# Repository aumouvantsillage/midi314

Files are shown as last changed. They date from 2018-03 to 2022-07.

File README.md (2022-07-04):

midi@3:14 is a home-made electronic keyboard for playing music.

This repository is no longer maintained.
Its content has been split into separate repositories available under the [Tiliosys](https://github.com/tiliosys) organization.

----

Keyboard
========

The midi@3:14 keyboard has the following characteristics:

* [Jankó](https://en.wikipedia.org/wiki/Jank%C3%B3_keyboard) layout with 3 rows of 14 keys.
* A *function key*, to assign special functions to the other keys.
* 5 potentiometers,
* USB-MIDI interface.

See the following files for more details:

* Keyboard [description](doc/Layout.md) and [layout](doc/Layout.svg).
* Printed circuit board [source files](hardware) and [bill of material](doc/BOM.md).

Firmware
========

The keyboard is equiped with an Arduino Pro Micro module.
The firmware converts user actions into MIDI events using the [MIDIUSB](https://www.arduino.cc/en/Reference/MIDIUSB)
library.

The source files for the Arduino IDE are located in the [firmware](firmware) folder.

Software
========

The [software](software) folder contains the programs that can be run on a
computer to play music and record loops.

* [midi314-display](software/midi314-display) shows the current state of the keyboard (selected program, loop states).
* [midi314-looper](software/midi314-looper) records and plays loops, and is controlled by MIDI events from the keyboard.

These programs are written in Rust and use [Jack](http://jackaudio.org/) as
the audio and MIDI interface.

The [scripts](software/scripts) folder contains a sample configuration for using the
midi@3:14 keyboard and software with [fluidsynth](http://www.fluidsynth.org/).
Fluidsynth 2 is recommended for monophonic instruments and breath controller support.
The following commands in the fluidsynth shell :

```
setbreathmode 0 0 1 1
setlegatomode 0 1
```

TODO
====

* Add metronome.
* Use metronome as a reference for the looper.
* Overdub in looper.
* Add effects.
* Record loop to a file.
* Try alternative synthesizers.
* Find a solution for safe power-off.
* Raspberry Pi: reduce boot time.
* Raspberry Pi: fix unresponsive keyboard for several seconds on boot.
* Check issue with volume after recording several loops.

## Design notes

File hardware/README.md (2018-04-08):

This folder contains the KiCad project of the midi@3:14 keyboard PCB.

Issues
======

* The PCB has no mounting holes. They must be drilled manually.
* Potentiometers have been rotated by 180 degrees from their standard orientation.
  Bourns PTV09A potentiometers have a D-shaped shaft: you can use blank knobs, or knobs with a round hole and a set-screw.
* The spacing between potentiometers is too short.
  The knob diameter must be less than 19 mm.

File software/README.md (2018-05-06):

Dependencies
============

* ALSA
* jackd
* jack-plumbing (package jack-tools) or qjackctl
* a2jmidid
* fluidsynth

```
sudo apt install a2jmidid jack-tools fluidsynth
```

Building
========

Install the Rust tool chain:

```
curl https://sh.rustup.rs -sSf | sh
source $HOME/.cargo/env
```

Build applications:

```
cd software/midi314-display
cargo build --release

cd ../midi314-looper
cargo build --release
cd -
```

Install:

```
sudo software/scripts/install.sh
```

Running
=======

Execute the `midi314.sh` script from the command line.

```
midi314.sh
```

Press a key to stop.

Building and running headless on Raspberry Pi
=============================================

Starting from an official Raspbian Stretch Lite image.
Install the dependencies and build the applications as explained in
the previous sections.

Low-latency configuration
-------------------------

Edit `/etc/security/limits.d/audio.conf`:

```
@audio - rtprio 80
@audio - memlock unlimited
```

Check that the user `pi` belongs to the `audio` group.

Reduce the swap usage:

```
sudo /sbin/sysctl -w vm.swappiness=10
```

Headless Jackd
--------------

Install Jackd without the dbus dependency:
[Running Jackd headless](https://capocasa.net/jackd-headless)

```
sudo apt install build-essential libsamplerate0-dev libasound2-dev libsndfile1-dev git

git clone git://github.com/jackaudio/jack2.git
cd jack2

./waf configure --alsa --prefix=/usr/local --libdir=/usr/lib/arm-linux-gnueabihf
./waf
sudo ./waf install
```

LCD Display
-----------

In `/boot/config.txt`, uncomment the line:

```
dtparam=spi=on
```

Run on boot
-----------

To run `midi314.sh` automatically when the board boots, do the following:

```
sudo systemctl edit midi314 --force
```

Add the following content to the service definition:

```
[Unit]
Description=midi@3:14
After=multi-user.target

[Service]
Type=idle
Environment="DEVICE=hw:0"
Environment="INTERFACE=service"
Environment="PATH=/usr/local/bin:/usr/bin:/bin"
ExecStart=/usr/bin/midi314.sh
User=pi

[Install]
WantedBy=multi-user.target
```

Enable the service:

```
sudo systemctl enable midi314.service
sudo reboot
```

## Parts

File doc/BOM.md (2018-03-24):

Keyboard
========

| Description | Reference | Provider | Qty | Unit price (USD) | Total price (USD) | Unit price (EUR) | Total price (EUR) |
|:---|:---|:---|----:|---:|---:|---:|---:|
| [Cherry MX Red Keyswitch (Linear) PCB Mounted](http://www.wasdkeyboards.com/index.php/products/keyboard-parts/cherry-mx-red-keyswitch-mx1a-l1nw-linear.html) | MX1A-L1NW | [WASD](http://www.wasdkeyboards.com) |  50 | 0.75 | 37.50 | | |
| [Row 4, Size 1x1 Cherry MX Keycap](http://www.wasdkeyboards.com/index.php/products/blank-keycap-singles/row-4-size-1x1-cherry-mx-keycap.html), Beige | R4-1X1 | [WASD](http://www.wasdkeyboards.com) |  23 | 1.00 | 23.00 | | |
| [Row 4, Size 1x1 Cherry MX Keycap](http://www.wasdkeyboards.com/index.php/products/blank-keycap-singles/row-4-size-1x1-cherry-mx-keycap.html), Charcoal | R4-1X1 | [WASD](http://www.wasdkeyboards.com) |  18 | 1.00 | 18.00 | | |
| [Row 4, Size 1x1 Cherry MX Keycap](http://www.wasdkeyboards.com/index.php/products/blank-keycap-singles/row-4-size-1x1-cherry-mx-keycap.html), Orange | R4-1X1 | [WASD](http://www.wasdkeyboards.com) | 1 | 1.00 | 1.00 | | |
| Keyboard parts shipping, USPS - First-Class Package International Service, to France | R4-1X1 | [WASD](http://www.wasdkeyboards.com) | 1 | 23.50 | 23.50 | | |
| Printed Circuit Board | | [Elecrow](https://www.elecrow.com) | 1 | 30.47 | 30.47 | | |
| Printed Circuit Board shipping, Hong-Kong DHL, to France | | [Elecrow](https://www.elecrow.com) | 1 | 20.03 | 20.03 | | |
| Printed Circuit Board customs, Hong-Kong DHL, to France | | [Elecrow](https://www.elecrow.com) | 1 | | | 23.00 | 23.00 |
| Potentiometer, Bourns PTV09A series, 10 kOhm | PTV09A-4225F-B103 | [Farnell](http://fr.farnell.com/) | 5 | | | 0.97 | 4.85 |
| Diodes | 1N4148 | [Farnell](http://fr.farnell.com/) |  50 | | | 0.682 | 3.41 |
| Components, shipping | | [Farnell](http://fr.farnell.com/) | 1 | | | 6.90 | 6.90 |
| Components, VAT | | [Farnell](http://fr.farnell.com/) | 1 | | | 3.44 | 3.44 |
| Arduino Leonardo Pro Micro ATmega32U4 | | [Chip and love](https://www.chipandlove.ch) | 1 | | | 13.00 | 13.00 |
| Knobs | | | 5 | | | | |

Computer
========

| Reference | Qty | Function |
|:---|----:|:---|
| Raspberry Pi 3 | 1 | MIDI instrument |
| LCD display | 1 | |
| Behringer U-Control UCA222 | 1 | USB sound card  |
| USB cable A-micro B | 1 | Arduino to Pi |

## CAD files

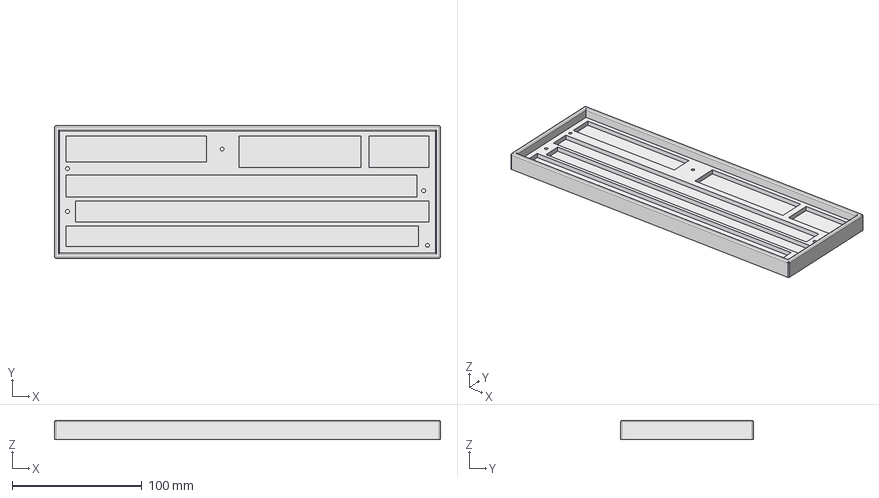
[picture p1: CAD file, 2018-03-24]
cad/midi314.fcstd
297.0 x 102.0 x 15.0 mm

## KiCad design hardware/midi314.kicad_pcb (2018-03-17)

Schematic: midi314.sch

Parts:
D11, D12, D13, D14, D15, D16, D17, D21, D22, D23, D24, D25, D26, D27, D31, D32, D33, D34, D35, D36, D37, D41, D42, D43, D44, D45, D46, D47, D51, D52, D53, D54, D55, D56, D57, D61, D62, D63, D64, D65, D66, D67: 1N4148; D_DO-35_SOD27_P10.16mm_Horizontal
RV1, RV2, RV3, RV4, RV5: POT; Potentiometer_Bourns_PTV09A-1_Single_Vertical
SW11, SW12, SW13, SW14, SW15, SW16, SW17, SW21, SW22, SW23, SW24, SW25, SW26, SW27, SW31, SW32, SW33, SW34, SW35, SW36, SW37, SW41, SW42, SW43, SW44, SW45, SW46, SW47, SW51, SW52, SW53, SW54, SW55, SW56, SW57, SW61, SW62, SW63, SW64, SW65, SW66, SW67: SW_Push; SW_Cherry_MX1A_1.00u_PCB
U1: Arduino_Pro_Micro; DIP-24_W15.24mm

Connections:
+5V: RV1.1, RV2.1, RV3.1, RV4.1, RV5.1, U1.21 (VCC)
COL1: D11.1, D21.1, D31.1, D41.1, D51.1, D61.1, U1.13 (D10)
COL2: D12.1, D22.1, D32.1, D42.1, D52.1, D62.1, U1.14 (D16)
COL3: D13.1, D23.1, D33.1, D43.1, D53.1, D63.1, U1.15 (D14)
COL4: D14.1, D24.1, D34.1, D44.1, D54.1, D64.1, U1.16 (D15)
COL5: D15.1, D25.1, D35.1, D45.1, D55.1, D65.1, U1.17 (D18)
COL6: D16.1, D26.1, D36.1, D46.1, D56.1, D66.1, U1.18 (D19)
COL7: D17.1, D27.1, D37.1, D47.1, D57.1, D67.1, U1.19 (D20)
GND: RV1.3, RV2.3, RV3.3, RV4.3, RV5.3, U1.4 (GND)
unnamed: D11.2, SW11.1
unnamed: D12.2, SW12.1
unnamed: D13.2, SW13.1
unnamed: D14.2, SW14.1
unnamed: D15.2, SW15.1
unnamed: D16.2, SW16.1
unnamed: D17.2, SW17.1
unnamed: D21.2, SW21.1
unnamed: D22.2, SW22.1
unnamed: D23.2, SW23.1
unnamed: D24.2, SW24.1
unnamed: D25.2, SW25.1
unnamed: D26.2, SW26.1
unnamed: D27.2, SW27.1
unnamed: D31.2, SW31.1
unnamed: D32.2, SW32.1
unnamed: D33.2, SW33.1
unnamed: D34.2, SW34.1
unnamed: D35.2, SW35.1
unnamed: D36.2, SW36.1
unnamed: D37.2, SW37.1
unnamed: D41.2, SW41.1
unnamed: D42.2, SW42.1
unnamed: D43.2, SW43.1
unnamed: D44.2, SW44.1
unnamed: D45.2, SW45.1
unnamed: D46.2, SW46.1
unnamed: D47.2, SW47.1
unnamed: D51.2, SW51.1
unnamed: D52.2, SW52.1
unnamed: D53.2, SW53.1
unnamed: D54.2, SW54.1
unnamed: D55.2, SW55.1
unnamed: D56.2, SW56.1
unnamed: D57.2, SW57.1
unnamed: D61.2, SW61.1
unnamed: D62.2, SW62.1
unnamed: D63.2, SW63.1
unnamed: D64.2, SW64.1
unnamed: D65.2, SW65.1
unnamed: D66.2, SW66.1
unnamed: D67.2, SW67.1
unnamed: RV1.2, U1.7 (D4)
unnamed: RV2.2, U1.9 (D6)
unnamed: RV3.2, U1.11 (D8)
unnamed: RV4.2, U1.12 (D9)
unnamed: RV5.2, U1.20 (D21)
ROW1: SW11.2, SW12.2, SW13.2, SW14.2, SW15.2, SW16.2, SW17.2, U1.10 (D7)
ROW2: SW21.2, SW22.2, SW23.2, SW24.2, SW25.2, SW26.2, SW27.2, U1.8 (D5)
ROW3: SW31.2, SW32.2, SW33.2, SW34.2, SW35.2, SW36.2, SW37.2, U1.6 (D3)
ROW4: SW41.2, SW42.2, SW43.2, SW44.2, SW45.2, SW46.2, SW47.2, U1.5 (D2)
ROW5: SW51.2, SW52.2, SW53.2, SW54.2, SW55.2, SW56.2, SW57.2, U1.2 (D0)
ROW6: SW61.2, SW62.2, SW63.2, SW64.2, SW65.2, SW66.2, SW67.2, U1.1 (D1)

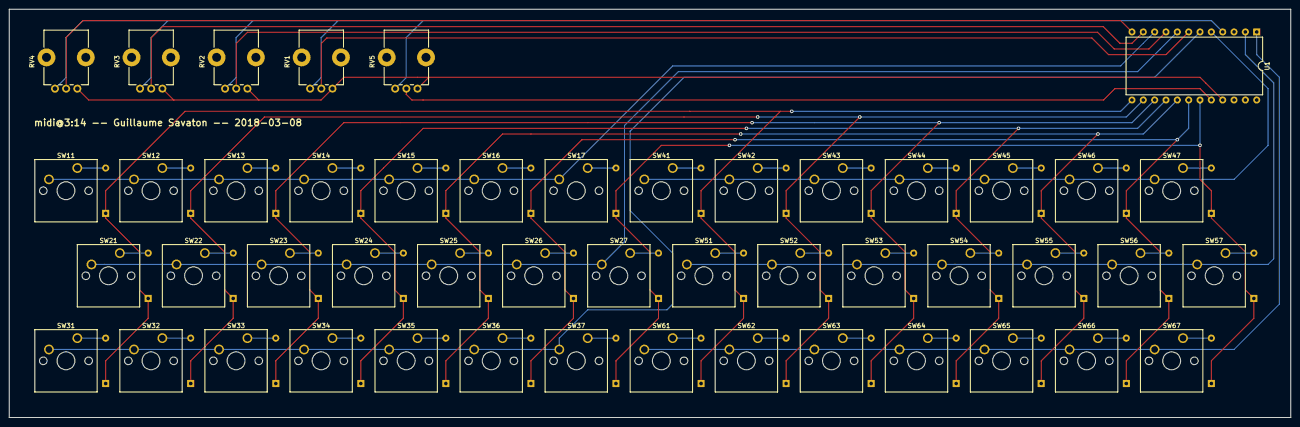
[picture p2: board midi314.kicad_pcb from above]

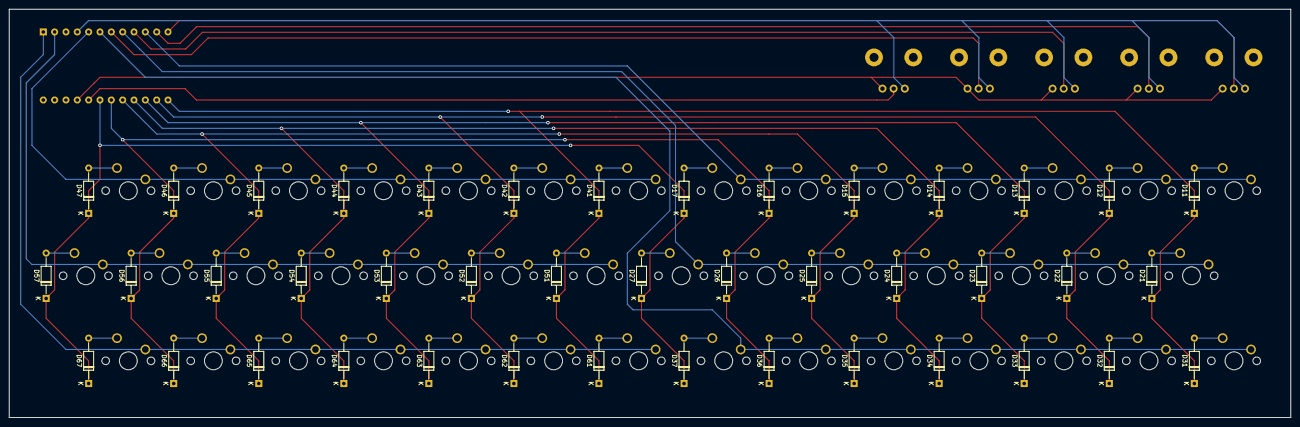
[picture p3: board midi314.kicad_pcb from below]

Board: 2 copper layers, 287.0 x 91.4 mm, 90 parts (42 on the bottom side), 62 nets.

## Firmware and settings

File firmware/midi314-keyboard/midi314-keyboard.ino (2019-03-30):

#include <pitchToNote.h>
#include <TimerThree.h>
#include <midi314.h>

// Pins connected to each row of the keyboard (from top to bottom).
static const byte rowPins[] = {7, 5, 3, 2, 0, 1};

// Pins connected to each column of the keyboard (from left to right).
static const byte colPins[] = {10, 16, 14, 15, 18, 19, 20};

// Pins connected to each potentiometer (from left to right).
static const byte potPins[] = {A9, A8, A7, A6, A3};

// The number of keyboard rows.
#define ROWS sizeof(rowPins)

// The number of keyboard columns.
#define COLS sizeof(colPins)

// The step between consecutive potetiometer stops.
#define POT_STEP 8

// The hysteresis threshold to update the potentiometer value.
#define POT_MARGIN 2

// The number of potentiometers.
#define POTS sizeof(potPins)

// The time to validate a steady state of a key, in milliseconds.
#define BOUNCE_TIME_MS 5

// The number of consecutive milliseconds in the pressed state for each key.
static byte keyPressedTimeMs[ROWS][COLS];

// The number of consecutive milliseconds in the released state for each key.
static byte keyReleasedTimeMs[ROWS][COLS];

// The pressed state for each key after debouncing.
static bool keyPressed[ROWS][COLS];

// The default pitch associated with each key.
static const byte keyNotes[ROWS][COLS] = {
    pitchC3,  pitchD3,  pitchE3,  pitchG3b, pitchA3b, pitchB3b, pitchC4,  // Top row, left
    pitchD3b, pitchE3b, pitchF3,  pitchG3,  pitchA3,  pitchB3,  pitchD4b, // Middle row, left
    pitchC3,  pitchD3,  pitchE3,  pitchG3b, pitchA3b, pitchB3b, pitchC4,  // Bottom row, left
    pitchD4,  pitchE4,  pitchG4b, pitchA4b, pitchB4b, pitchC5,  pitchD5,  // Top row, right
    pitchE4b, pitchF4,  pitchG4,  pitchA4,  pitchB4,  pitchD5b, pitchE5b, // Middle row, right
    pitchD4,  pitchE4,  pitchG4b, pitchA4b, pitchB4b, pitchC5,  pitchD5   // Bottom row, right
};

// The percussion number associated with each key.
// Not used: 58, 69, 71, 72, 73, 74, 75
static const byte keyPerc[ROWS][COLS] = {
    0,  61, 60, 64, 63, 62, 66, // Top row, left
    42, 44, 46, 49, 51, 52, 55, // Middle row, left
    35, 36, 38, 40, 37, 41, 43, // Bottom row, left
    65, 68, 67, 77, 76, 79, 78, // Top row, right
    57, 59, 54, 53, 56, 80, 81, // Middle row, right
    45, 47, 48, 50, 69, 70, 39  // Bottom row, right
};

// Indicates whether a note is playing for each key.
static bool keyNoteOn[ROWS][COLS];

// Function ids for keys.
enum {
    KEY_NONE   = 0x00,

    KEY_FN     = 0xFF,

    KEY_OCTAVE = 0x10,
    KEY_SEMI   = 0x20,
    KEY_PROG   = 0x30,
    KEY_TEMPO  = 0x40,
    KEY_LOOP   = 0x50,
    KEY_PERC   = 0x60,
    KEY_MONO   = 0x70,
    KEY_PANIC  = 0x80,

    // Multi-purpose Up/Down key codes, to be combined with
    // KEY_OCTAVE, KEY_SEMI, KEY_PROG, KEY_TEMPO.
    KEY_DOWN   = 0x0F,
    KEY_UP     = 0x0E,

    // Loop control key codes, to be combined with KEY_LOOP.
    KEY_DEL    = 0x0F,
    KEY_SOLO   = 0x0E,
    KEY_ALL    = 0x0D
};

// The special functions associated with each key.
static const byte keyFn[ROWS][COLS] = {
    KEY_FN,            KEY_OCTAVE|KEY_DOWN, KEY_OCTAVE|KEY_UP,  KEY_TEMPO|KEY_DOWN, KEY_TEMPO|KEY_NONE, KEY_TEMPO|KEY_UP,   KEY_NONE,        // Top row, left
    KEY_SEMI|KEY_DOWN, KEY_SEMI  |KEY_UP,   KEY_PROG  |0,       KEY_PROG |1,        KEY_PROG |2,        KEY_PROG |3,        KEY_PROG|4,      // Middle row, left
    KEY_LOOP|KEY_DEL,  KEY_LOOP  |KEY_SOLO, KEY_LOOP  |KEY_ALL, KEY_LOOP |0,        KEY_LOOP |1,        KEY_LOOP |2,        KEY_LOOP|3,      // Bottom row, left
    KEY_NONE,          KEY_NONE,            KEY_NONE,           KEY_NONE,           KEY_NONE,           KEY_MONO,           KEY_PERC,        // Top row, right
    KEY_PROG|5,        KEY_PROG  |6,        KEY_PROG  |7,       KEY_PROG |8,        KEY_PROG |9,        KEY_PROG |KEY_DOWN, KEY_PROG|KEY_UP, // Middle row, right
    KEY_LOOP|4,        KEY_LOOP  |5,        KEY_LOOP  |6,       KEY_LOOP |7,        KEY_LOOP |8,        KEY_NONE,           KEY_PANIC        // Bottom row, right
};

#define FN_KEY_PRESSED keyPressed[0][0]
#define DEL_KEY_PRESSED keyPressed[2][0]
#define SOLO_KEY_PRESSED keyPressed[2][1]

// The value of each potentiometer, range 0 to 127.
static byte potValues[POTS];

// The default note velocity.
#define VELOCITY 127

// The pitch of the bottom-left key.
static int pitchOffset;

// The MIDI program mapped to key P1.
static int midiProgramOffset;

// The current MIDI program number.
static byte midiProgram;

// The number of the current loop.
static byte currentLoop;

// The number of supported loops.
#define LOOPS 9

enum {
    LOOP_EMPTY,
    LOOP_RECORDING,
    LOOP_PLAYING,
    LOOP_MUTED
};

// The current state of each loop.
static byte loopState[LOOPS];

// The current MIDI channel.
static byte midiChannel;

// The current mono/polyphonic mode.
static bool monoMode;

// The default assignment of potentiometers.
static const byte potFn[] = {POT_VOLUME, POT_PAN, POT_REVERB, POT_CHORUS, POT_MODULATION};

static void scan() {
    // All column output pins are supposed to be high before scanning.
    // Scan the keyboard column-wise.
    for (int c = 0; c < COLS; c ++) {
        // Enable the current column.
        digitalWrite(colPins[c], 0);

        // Read the current state of each key in the current column.
        for (int r = 0; r < ROWS; r ++) {
            bool keyStatus = !digitalRead(rowPins[r]);

            if (keyStatus) {
                // A key-pressed event is valid if the key was released for a sufficient time.
                if (!keyPressed[r][c] && keyReleasedTimeMs[r][c] == BOUNCE_TIME_MS) {
                    keyPressed[r][c] = true;
                    midi314.pushEvent(PRESS_EVENT, r, c);
                }

                // Count the time in the pressed state. Reset the released state counter.
                if (keyPressedTimeMs[r][c] < BOUNCE_TIME_MS) {
                    keyPressedTimeMs[r][c] ++;
                }

                keyReleasedTimeMs[r][c] = 0;
            }
            else {
                // A key-released event is valid if the key was pressed for a sufficient time.
                if (keyPressed[r][c] && keyPressedTimeMs[r][c] == BOUNCE_TIME_MS) {
                    keyPressed[r][c] = false;
                    midi314.pushEvent(RELEASE_EVENT, r, c);
                }

                // Count the time in the released state. Reset the pressed state counter.
                if (keyReleasedTimeMs[r][c] < BOUNCE_TIME_MS) {
                    keyReleasedTimeMs[r][c] ++;
                }

                keyPressedTimeMs[r][c] = 0;
            }
        }

        // Disable the current column.
        digitalWrite(colPins[c], 1);
    }

    // Read potentiometer values.
    for (int p = 0; p < POTS; p ++) {
        int analogPrev = (int)potValues[p] * POT_STEP;
        int analog = analogRead(potPins[p]);
        if (analog > analogPrev + POT_STEP + POT_MARGIN ||
            analog < analogPrev - POT_MARGIN) {
            potValues[p] = analog / POT_STEP;
            midi314.pushEvent(POT_EVENT, p);
        }
    }
}

static inline int getMinPitch() {
    return pitchOffset + keyNotes[2][0];
}

static inline int getMaxPitch() {
    return pitchOffset + keyNotes[ROWS-2][COLS-1];
}

static bool isRecording;

static inline void stopRecording() {
    loopState[currentLoop] = LOOP_PLAYING;
    isRecording = false;
    midi314.controlChange(DEFAULT_MIDI_CHANNEL, MIDI_CC_CUSTOM_PLAY, currentLoop);
}

static inline void updatePitchOffset(int n) {
    if (n < 0 && getMinPitch() + n >= pitchA0 || n > 0 && getMaxPitch() + n <= pitchC8) {
        pitchOffset += n;
    }
    midi314.controlChange(DEFAULT_MIDI_CHANNEL, MIDI_CC_CUSTOM_SET_MIN_PITCH, getMinPitch());
}

static inline void updateMidiProgramOffset(int n) {
    int nextOffset = midiProgramOffset + n;
    if (nextOffset < 0) {
        midiProgramOffset = 120;
    }
    else if (nextOffset > 120) {
        midiProgramOffset = 0;
    }
    else {
        midiProgramOffset = nextOffset;
    }
    midi314.controlChange(DEFAULT_MIDI_CHANNEL, MIDI_CC_CUSTOM_SET_MIN_PROGRAM, midiProgramOffset);
}

static void playSolo(int n) {
    if (loopState[n] == LOOP_MUTED) {
        loopState[n] = LOOP_PLAYING;
    }
    for (int i = 0; i < LOOPS; i ++) {
        if (i != n && loopState[i] == LOOP_PLAYING) {
            loopState[i] = LOOP_MUTED;
        }
    }
    midi314.controlChange(DEFAULT_MIDI_CHANNEL, MIDI_CC_CUSTOM_SOLO, n);
}

static void playAllLoops() {
    // Unmute all muted loops.
    for (int i = 0; i < LOOPS; i ++) {
        if (loopState[i] == LOOP_MUTED) {
            loopState[i] = LOOP_PLAYING;
        }
    }
    midi314.controlChange(DEFAULT_MIDI_CHANNEL, MIDI_CC_CUSTOM_ALL, 0);
}

static inline void updateLoop(int n) {
    switch (loopState[n]) {
        case LOOP_EMPTY:
            if (!DEL_KEY_PRESSED && !isRecording) {
                loopState[n] = LOOP_RECORDING;
                currentLoop = n;
                isRecording = true;
                midi314.controlChange(DEFAULT_MIDI_CHANNEL, MIDI_CC_CUSTOM_RECORD, n);
            }
            break;
        case LOOP_PLAYING:
            if (DEL_KEY_PRESSED) {
                loopState[n] = LOOP_EMPTY;
                midi314.controlChange(DEFAULT_MIDI_CHANNEL, MIDI_CC_CUSTOM_DELETE, n);
            }
            else if (SOLO_KEY_PRESSED) {
                playSolo(n);
            }
            else {
                loopState[n] = LOOP_MUTED;
                midi314.controlChange(DEFAULT_MIDI_CHANNEL, MIDI_CC_CUSTOM_MUTE, n);
            }
            break;
        case LOOP_MUTED:
            if (DEL_KEY_PRESSED) {
                loopState[n] = LOOP_EMPTY;
                midi314.controlChange(DEFAULT_MIDI_CHANNEL, MIDI_CC_CUSTOM_DELETE, n);
            }
            else if (SOLO_KEY_PRESSED) {
                playSolo(n);
            }
            else {
                loopState[n] = LOOP_PLAYING;
                midi314.controlChange(DEFAULT_MIDI_CHANNEL, MIDI_CC_CUSTOM_PLAY, n);
            }
            break;
    }
}

static void forcePotEvents() {
    for (int p = 0; p < POTS; p ++) {
        midi314.pushEvent(POT_EVENT, p);
    }
}

static void processFunctionKey(int r, int c) {
    byte fn  = keyFn[r][c] & 0xF0;
    byte arg = keyFn[r][c] & 0x0F;

    switch (fn) {
        case KEY_OCTAVE:
            updatePitchOffset(arg == KEY_UP ? 12 : -12);
            break;
        case KEY_SEMI:
            updatePitchOffset(arg == KEY_UP ? 1 : -1);
            break;
        case KEY_PERC:
            if (midiChannel == DEFAULT_MIDI_CHANNEL) {
                midiChannel = PERC_MIDI_CHANNEL;
                midi314.controlChange(DEFAULT_MIDI_CHANNEL, MIDI_CC_CUSTOM_PERCUSSION, 127);
            }
            else {
                midiChannel = DEFAULT_MIDI_CHANNEL;
                midi314.controlChange(DEFAULT_MIDI_CHANNEL, MIDI_CC_CUSTOM_PERCUSSION, 0);
            }
            forcePotEvents();
            break;
        case KEY_MONO:
            monoMode = !monoMode;
            if (monoMode) {
                midi314.controlChange(midiChannel, MIDI_CC_MONO_MODE_ON, 0);
            }
            else {
                midi314.controlChange(midiChannel, MIDI_CC_POLY_MODE_ON, 0);
            }
            break;
        case KEY_PROG:
            if (midiChannel != PERC_MIDI_CHANNEL) {
                switch (arg) {
                    case KEY_DOWN:
                        updateMidiProgramOffset(-10);
                        break;
                    case KEY_UP:
                        updateMidiProgramOffset(10);
                        break;
                    default:
                        midiProgram = (midiProgramOffset + arg) % 128;
                        midi314.programChange(midiChannel, midiProgram);
                }
            }
            break;
        case KEY_TEMPO:
            // TODO Not implemented.
            break;
        case KEY_LOOP:
            switch (arg) {
                case KEY_ALL:
                    playAllLoops();
                    break;
                case KEY_SOLO:
                case KEY_DEL:
                    break;
                default:
                    updateLoop(arg);
            }
            break;
        case KEY_PANIC:
            midi314.controlChange(DEFAULT_MIDI_CHANNEL, MIDI_CC_ALL_NOTES_OFF, 0);
            break;
    }
}

static inline byte getNote(int r, int c) {
    return midiChannel == PERC_MIDI_CHANNEL ?
        keyPerc[r][c] :
        pitchOffset + keyNotes[r][c];
}

static void processEvents() {
    while (midi314.hasEvent()) {
        Event evt;
        midi314.pullEvent(&evt);

        byte potValue;

        switch (evt.kind) {
            case POT_EVENT:
                midi314.processPotEvent(midiChannel, potFn[evt.row], potValues[evt.row]);
                break;

            case PRESS_EVENT:
                if (keyFn[evt.row][evt.col] == KEY_FN) {
                    if (isRecording) {
                        stopRecording();
                    }
                }
                else if (FN_KEY_PRESSED) {
                    processFunctionKey(evt.row, evt.col);
                }
                else {
                    keyNoteOn[evt.row][evt.col] = true;
                    midi314.noteOn(midiChannel, getNote(evt.row, evt.col), VELOCITY);
                }
                break;

            case RELEASE_EVENT:
                if (keyNoteOn[evt.row][evt.col]) {
                    keyNoteOn[evt.row][evt.col] = false;
                    midi314.noteOff(midiChannel, getNote(evt.row, evt.col), VELOCITY);
                }
                break;
        }
    }
}

static void reset() {
    midi314.reset();

    // Read the initial potentiometer values.
    for (int p = 0; p < POTS; p ++) {
        potValues[p] = analogRead(potPins[p]) / POT_STEP;
        midi314.pushEvent(POT_EVENT, p);
    }

    pitchOffset = 0;
    midiChannel = DEFAULT_MIDI_CHANNEL;
    midiProgramOffset = 0;
    midiProgram = 0;
    currentLoop = 0;
    isRecording = false;
    monoMode = false;

    // FIXME send MIDI events to ensure this state is consistent with synth

    for (int l = 0; l < LOOPS; l ++) {
        loopState[l] = LOOP_EMPTY;
    }

    Serial.println("Ready");
}

void setup() {
    // Keyboard rows are attached to input pins with pull-ups.
    for (int r = 0; r < ROWS; r ++) {
        pinMode(rowPins[r], INPUT_PULLUP);
    }

    // Keyboard columns are attached to output pins.
    // We write 1 to each column to disable it.
    for (int c = 0; c < COLS; c ++) {
        pinMode(colPins[c], OUTPUT);
        digitalWrite(colPins[c], 1);
    }

    Serial.begin(115200);

    reset();

    // Call the scan function every millisecond.
    Timer3.initialize(1000);
    Timer3.attachInterrupt(scan);
}

void loop() {
    processEvents();
    midi314.flushMidi();

    if (Serial.available() > 0) {
        // TODO More configurations via the serial line.
        char c = Serial.read();
        if (c == 'R') {
            reset();
        }
    }
}

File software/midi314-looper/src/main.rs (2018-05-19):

extern crate jack;
extern crate midi314;

use std::{thread, time};
use midi314::{Keyboard, LoopManager, LoopState};

#[derive(Clone)]
struct Loop {
    state : LoopState,
    state_prev : LoopState,
    transition_time : usize,
    samples_1 : Vec<f32>,
    samples_2 : Vec<f32>
}

impl Loop {
    fn new(l : usize) -> Self {
        Self {
            state           : LoopState::Empty,
            state_prev      : LoopState::Empty,
            transition_time : 0,
            samples_1       : vec![0.0 ; l],
            samples_2       : vec![0.0 ; l]
        }
    }

    fn set_state(&mut self, time : usize, state : LoopState) {
        self.state = state;
        self.transition_time = time;
    }

    fn run(&mut self, from : usize, to : usize, cursor : usize, in_1 : &[f32], in_2 : &[f32], out_1 : &mut [f32], out_2 : &mut [f32]) {
        match self.state {
            LoopState::Empty =>
                if self.state_prev != LoopState::Empty {
                    // Clear the loop buffer to delete.
                    let zeros = vec![0.0 ; self.samples_1.len()];
                    self.samples_1.copy_from_slice(&zeros);
                    self.samples_2.copy_from_slice(&zeros);
                },
            LoopState::Recording =>
                if self.state_prev != LoopState::Recording {
                    let in_1 = &in_1[self.transition_time..];
                    let in_2 = &in_2[self.transition_time..];
                    let cursor = cursor + self.transition_time;
                    self.record(from, to, cursor, in_1, in_2);
                }
                else {
                    self.record(from, to, cursor, in_1, in_2)
                },
            LoopState::Playing => {
                if self.state_prev == LoopState::Recording {
                    // When transitioning from the Recording to the Playing state,
                    // finish recording the beginning of the input buffer (until transition time)
                    // into the loop buffer at the cursor,
                    let in_1 = &in_1[0..self.transition_time];
                    let in_2 = &in_2[0..self.transition_time];
                    self.record(from, to, cursor, in_1, in_2);
                }
                if self.state_prev != LoopState::Playing {
                    // When entering the Playing state, start playing from the transition time
                    // into the end of the output buffer.
                    let out_1 = &mut out_1[self.transition_time..];
                    let out_2 = &mut out_2[self.transition_time..];
                    let cursor = cursor + self.transition_time;
                    self.play(from, to, cursor, out_1, out_2)
                }
                else {
                    self.play(from, to, cursor, out_1, out_2)
                }
            },
            _ => ()
        }

        self.state_prev = self.state;
    }

    fn record(&mut self, from : usize, to : usize, cursor : usize, in_1 : &[f32], in_2 : &[f32]) {
        let length = if to == 0 {
            self.samples_1.len()
        }
        else {
            to
        };

        let mut in_len = in_1.len();
        let mut in_index = 0;
        let mut cursor = cursor;

        while in_len > 0 {
            let copy_len = if cursor + in_len < length {
                in_len
            }
            else {
                length - cursor
            };

            let src_1  = &in_1[in_index .. in_index + copy_len];
            let src_2  = &in_2[in_index .. in_index + copy_len];
            let dest_1 = &mut self.samples_1[cursor .. cursor + copy_len];
            let dest_2 = &mut self.samples_2[cursor .. cursor + copy_len];
            dest_1.copy_from_slice(src_1);
            dest_2.copy_from_slice(src_2);

            in_len   -= copy_len;
            in_index += copy_len;
            cursor   += copy_len;
            if cursor == length {
                cursor = from;
            }
        }
    }

    fn play(&self, from : usize, to : usize, cursor : usize, out_1 : &mut [f32], out_2 : &mut [f32]) {
        let mut cursor = cursor;
        for k in 0 .. out_1.len() {
            if cursor >= to {
                cursor -= to - from;
            }
            out_1[k] += self.samples_1[cursor];
            out_2[k] += self.samples_2[cursor];
            cursor += 1;
        }
    }
}

#[derive(PartialEq, PartialOrd)]
enum LooperState {
    Idle,
    WaitingFirstNote,
    RecordingFirstLoop,
    Running
}

struct Looper {
    state     : LooperState,
    loops     : Vec<Loop>,
    from      : usize,
    to        : usize,
    cursor    : usize,
    threshold : f32
}
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

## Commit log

2018-03-08 Hardware design
    [midi314-B.Cu.gbl, midi314-B.Mask.gbs, midi314-B.SilkS.gbo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]
2018-03-17 Added key dimension
    [midi314.kicad_pcb]
2018-03-18 Firmware: use timer interrupt to scan keyboard
2018-03-18 Added Arduino libraries
2018-03-24 Added mechanical drawings
    [midi314.fcstd]
2018-03-27 Renamed case folder
    [midi314.fcstd]
2018-04-01 Reset the keyboard using the serial interface
    [midi314.ino]
2018-04-08 Renamed folders
    [midi314-B.Cu.gbl, midi314-B.Mask.gbs, midi314-B.SilkS.gbo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]
2018-04-15 Fixed solo and all modes
    [lib.rs, main.rs, midi314.ino]
2018-04-27 Sample rate and build doc
2018-05-02 Added error handling to PCD8544
    [lib.rs, main.rs]
2018-05-05 Fixed LCD character print
    [lib.rs]
2018-05-05 Fixed glitches in LCD
    [main.rs]
2018-05-05 Set channel props from pots when changing MIDI channel
2018-05-06 Fix in set_pixel in portrait
    [lib.rs, main.rs]
2018-05-07 Prevent multiple loops marked as recording
    [midi314.ino]
2019-01-27 Firmware: Using event queue between main loop and interrupt.
2019-02-10 Added modulation wheel MIDI event to joystick
2019-02-19 Map both directions of the joystick to the pitch bend function
